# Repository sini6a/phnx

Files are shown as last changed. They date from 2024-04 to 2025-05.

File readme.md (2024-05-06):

# PHNX Keyboard

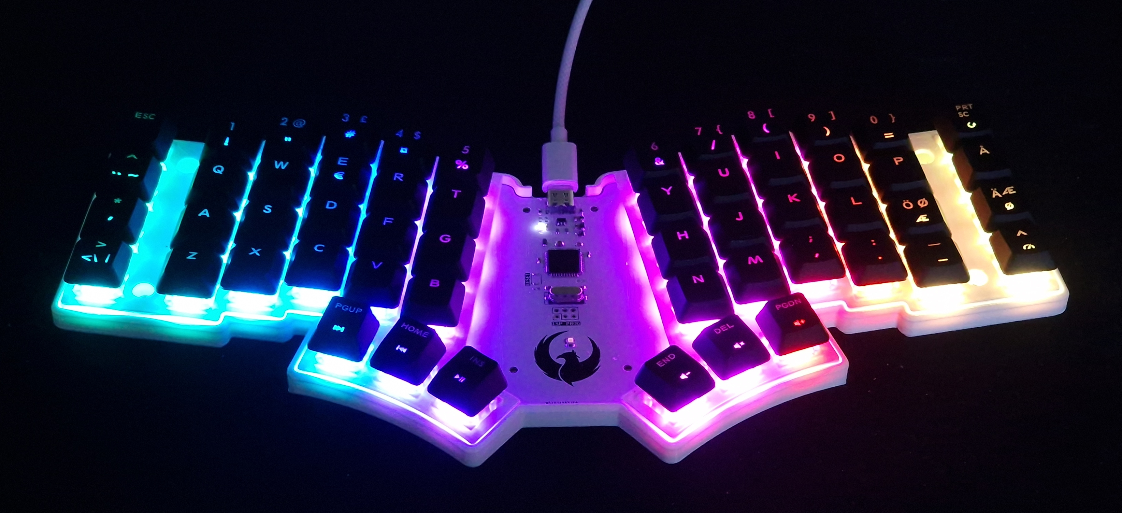
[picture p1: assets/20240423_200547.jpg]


PHNX is an ergonomic keyboard featuring 54 MX compatible switches. It is inspired by the Miryoku layout and includes one additional row at the top along with macro keys on both sides. Powered by the famous ATMega32U4 microcontroller, it features a Type C connector with ESD protection.

The keyboard is using QMK software and features an addressable LED on each key. Designed using KiCad 8, the boards were sponsored by [PCBWay](https://pcbway.com/), known for their excellent PCB manufacturing capabilities.

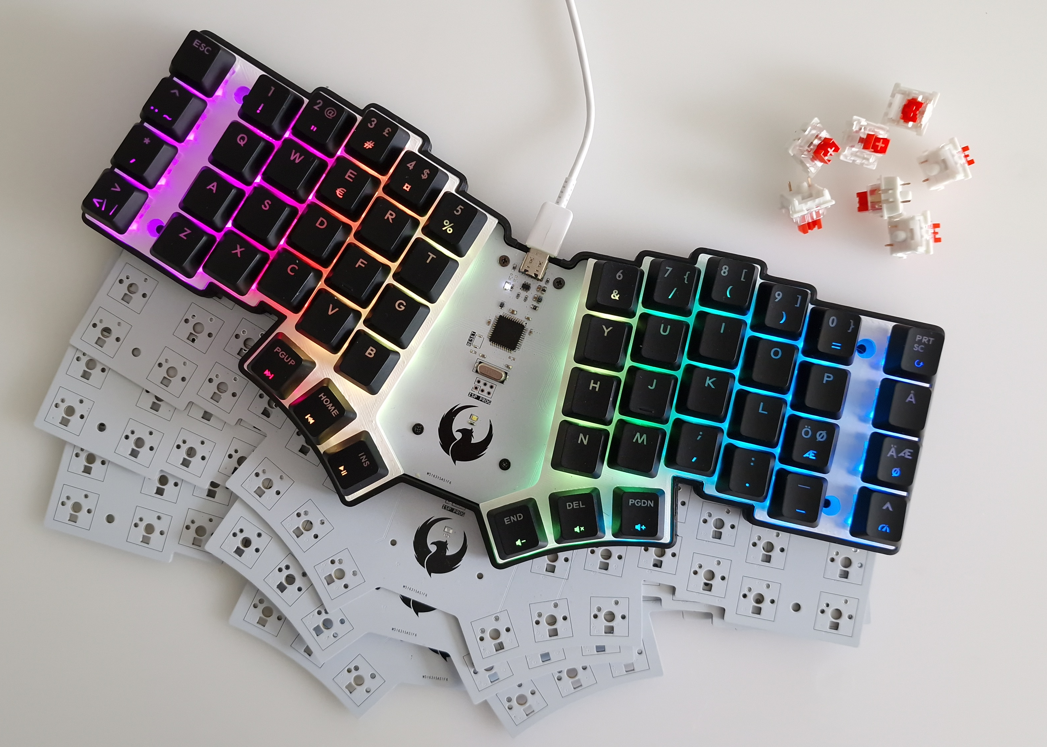
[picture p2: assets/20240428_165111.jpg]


## Project Structure

The project repository is structured as follows:

- **`kicad/`**: Contains PCB design files and schematics.
- **`gerbers/`**: Includes Gerber files essential for manufacturing.
- **`fimware/`**: Includes PHNX keyboard mappings and QMK files. This folder should be copied to your QMK directory and renamed to 'phnx'.
- **`case/`**: Consists of 3D print files for both the switch plates and the back cover of the keyboard.

The schematic is available in PDF format in the **`kicad/`** directory.

## Build Process

For a comprehensive overview of the schematic, board layout, and the build process, please refer to the following YouTube video:

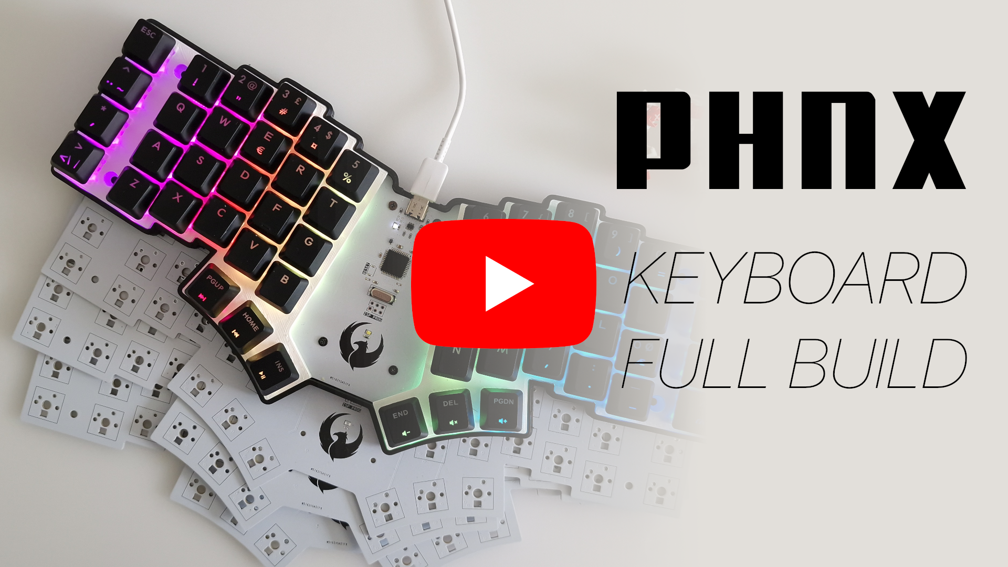
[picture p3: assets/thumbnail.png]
Thumbnail (https://www.youtube.com/watch?v=Z5Uw6cO_Igg)


## 3D Printed Parts

The case consists of two 3D printed parts. The two plates for each side to put switches on, and the bottom case which will fit the boards. The case has space for installing rubber pads for better grip.

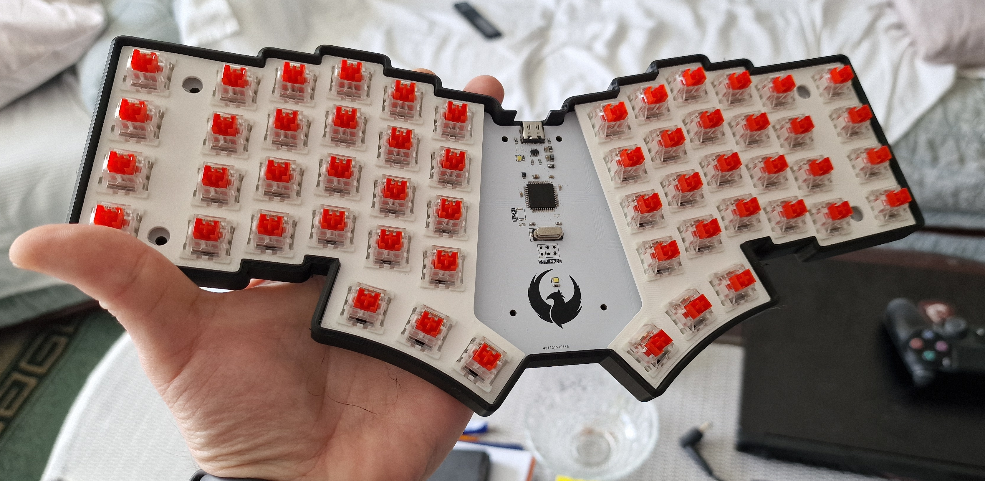
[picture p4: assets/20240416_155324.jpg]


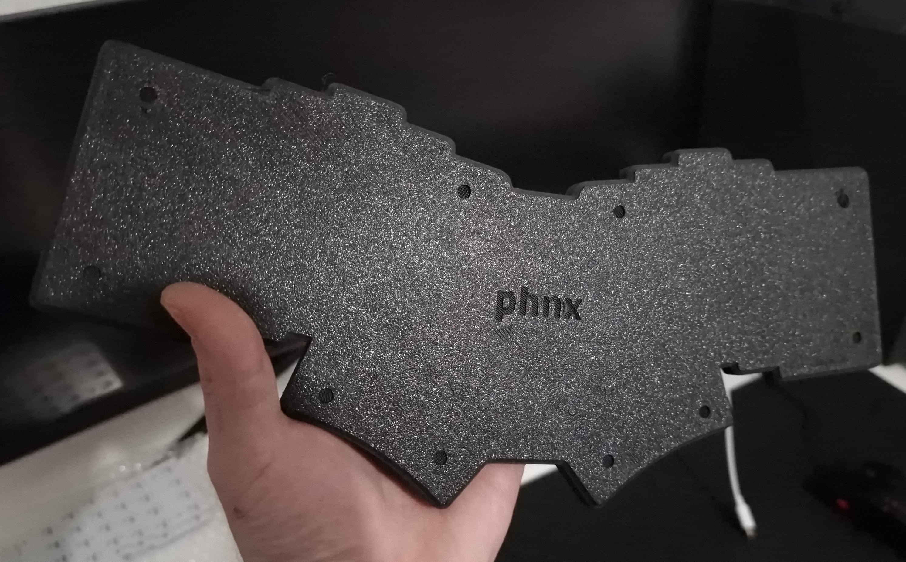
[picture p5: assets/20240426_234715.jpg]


## Contributing

Contributions to PHNX are welcome! Before making any changes, please ensure to open an issue to discuss the proposed modifications.

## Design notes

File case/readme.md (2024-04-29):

# 3D Files

The case is designed in Fusion 360 and the files are exported in STEP extension. 

For assembly we need 4xM2 screw inserts for the middle section of the case. The Component Cover needs redesign because it won't fit with the plates in place.

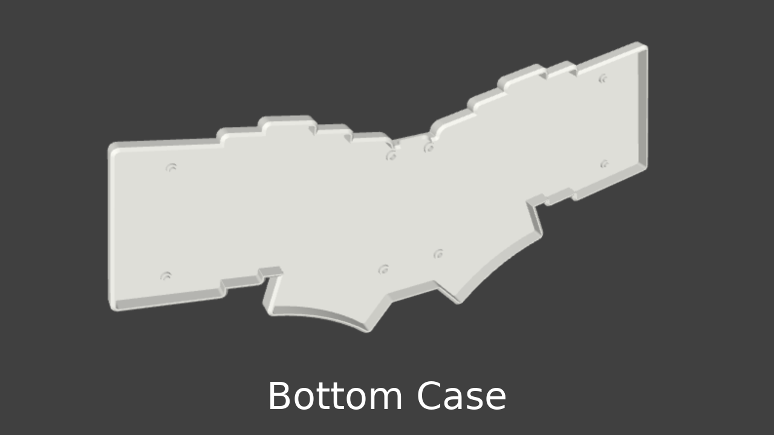
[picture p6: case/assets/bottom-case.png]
Bottom Case


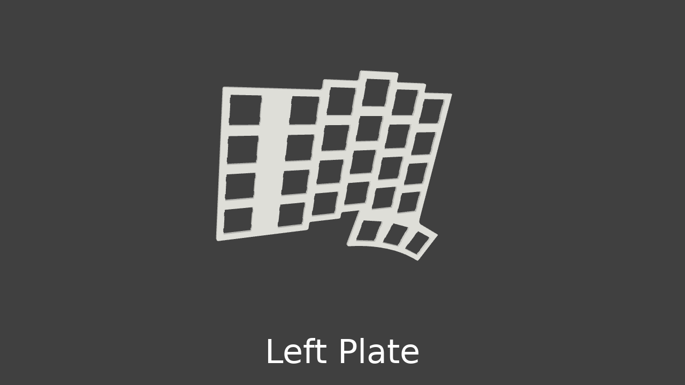
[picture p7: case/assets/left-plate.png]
Left Plate


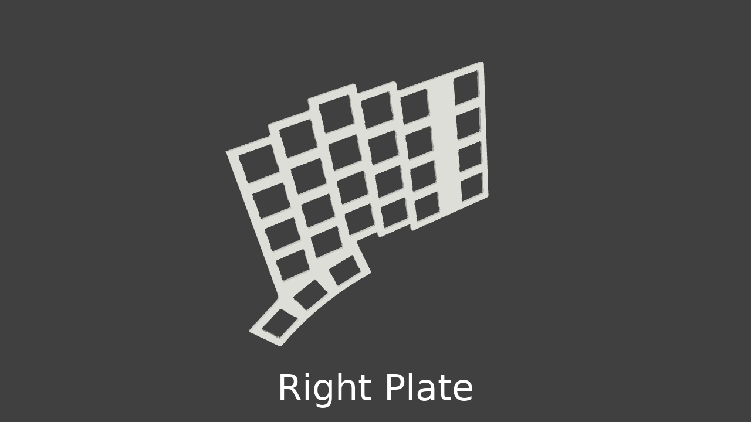
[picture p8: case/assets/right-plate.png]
Right Plate


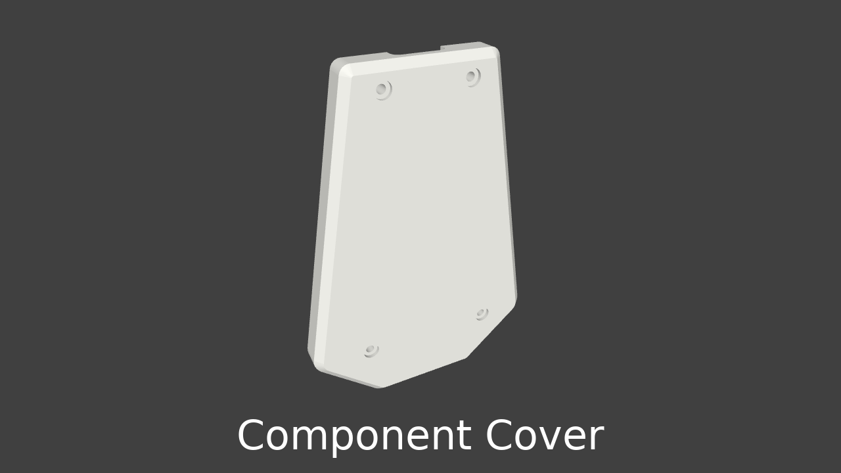
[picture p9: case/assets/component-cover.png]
Component Cover


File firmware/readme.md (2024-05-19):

# PHNX Firmware Files

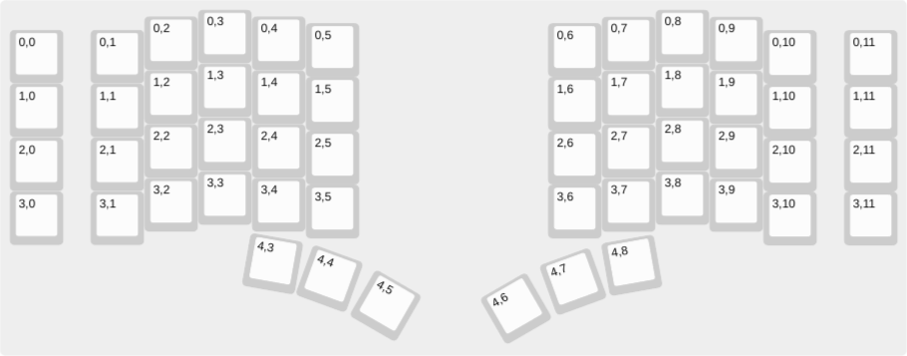
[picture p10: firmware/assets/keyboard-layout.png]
KLE


## Introduction

This directory contains firmware files for the PHNX keyboard, which is compatible with [QMK](https://github.com/qmk/qmk_firmware).

## Getting Started

To get started, follow these steps:

### 1. Clone QMK Firmware Repository

Ensure you have the latest version of QMK firmware on your local computer. Clone the QMK repository using the following command:

```bash
git clone https://github.com/qmk/qmk_firmware
```

### 2. Create PHNX Directory

Create a new directory named `phnx` in the `keyboards` directory in your local QMK:

```bash
mkdir qmk_firmware/keyboards/phnx
```

### 3. Copy Firmware Files

Copy the contents of the `firmware` directory from this repository to the newly created `phnx` directory in your QMK firmware repository:

```bash
cp -r path/to/phnx/firmware qmk_firmware/keyboards/phnx/
```

_Replace `path/to/phnx` with the actual path to the firmware directory in this repository._

## Compilation

Compile the keyboard firmware using the default or via keymap. You can do this using either the `make` command or the QMK client for Linux.

### Using Make

```bash
make phnx:default
```

or using `via` keymap:

```bash
make phnx:via
```

### Using QMK Client

```bash
qmk compile -kb phnx -km default
```

alternatively:

```bash
qmk compile -kb phnx -km via
```

## Flashing the Keyboard

Once the compilation is successful, you can proceed to flash the firmware onto the keyboard.

### Using Make

```bash
make phnx:default:flash
```

alternatively:

```bash
make phnx:via:flash
```

### Using QMK Client

```bash
qmk flash -kb phnx -km default
```

alternatively:

```bash
qmk flash -kb phnx -km via
```

**Note:** Depending on your system configuration, you may need to use `sudo` to flash the keyboard.

## Troubleshooting

If you encounter any issues during the compilation or flashing process, feel free to open an issue in this repository for assistance or check the official QMK repository.

Happy typing!

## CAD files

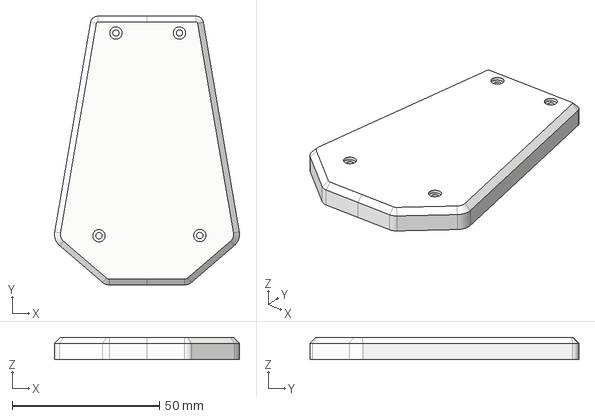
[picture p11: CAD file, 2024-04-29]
case/Component Cover.step
62.8 x 91.3 x 7.50 mm

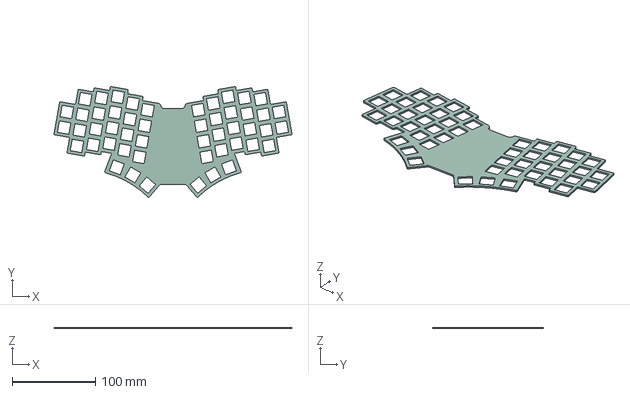
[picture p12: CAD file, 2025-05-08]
kicad/3D Exported/plate.step
286.3 x 133.4 x 1.60 mm

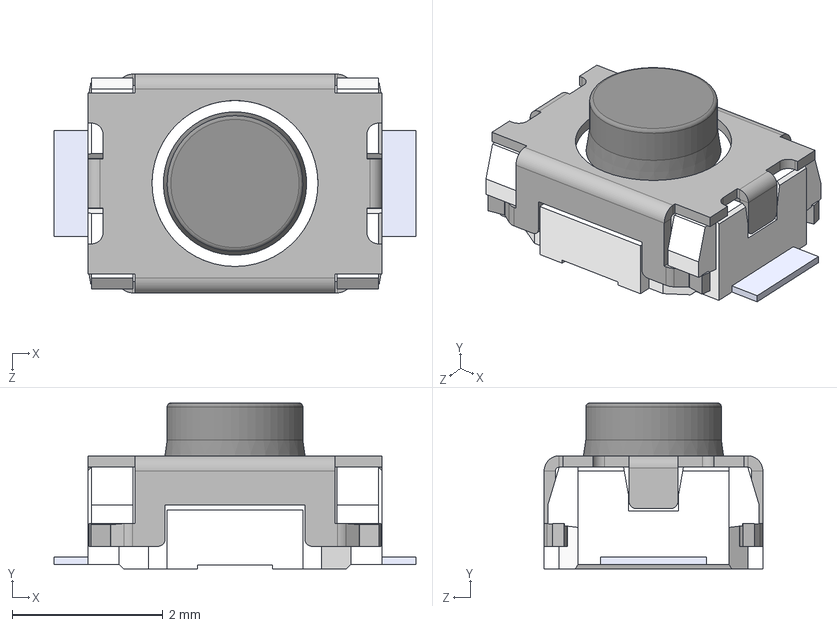
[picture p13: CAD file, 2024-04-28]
kicad/KiCad/3dmodels/SKRKAHE020--3DModel-STEP-56544.STEP
4.80 x 2.20 x 2.90 mm

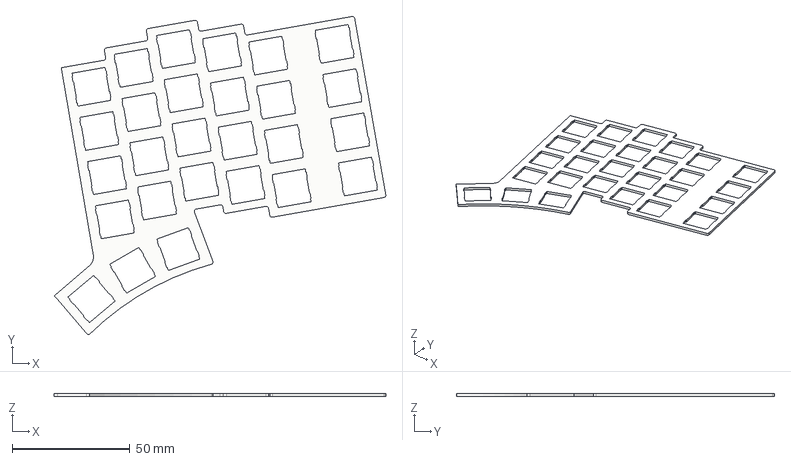
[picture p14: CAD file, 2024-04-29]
case/Right Plate.step
140.8 x 135.0 x 1.30 mm

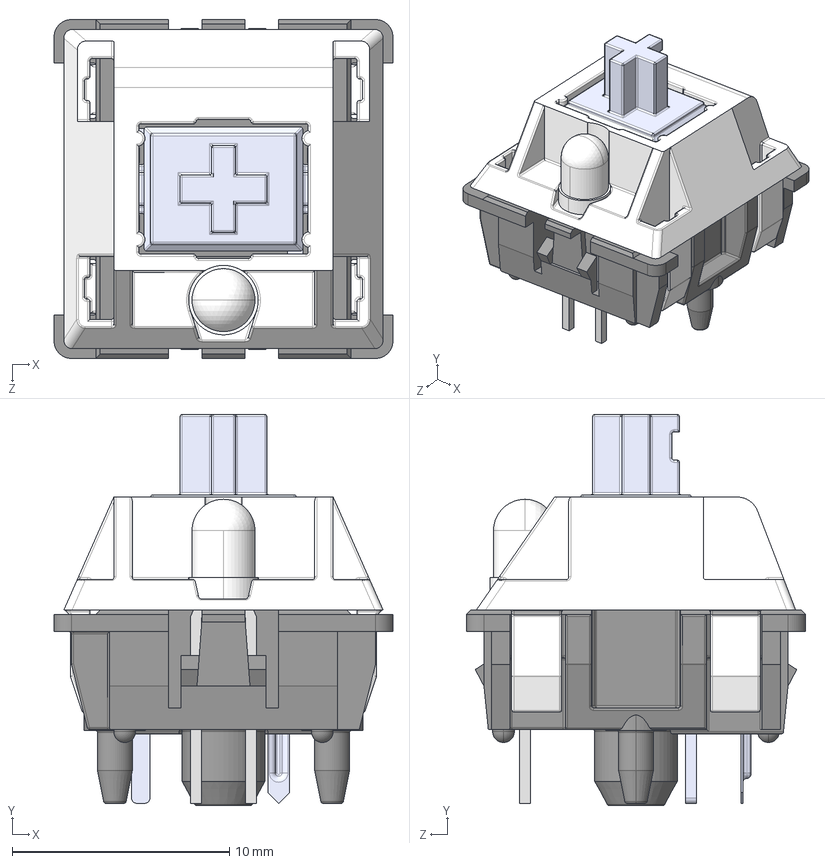
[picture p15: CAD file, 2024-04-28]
kicad/KiCad/3dmodels/Cherry MX.STEP
15.6 x 18.0 x 15.6 mm
Bottom
Pulsador
Top
Pieza5^Cherry MX
Pin1
Pin2
Led 3mm_trans

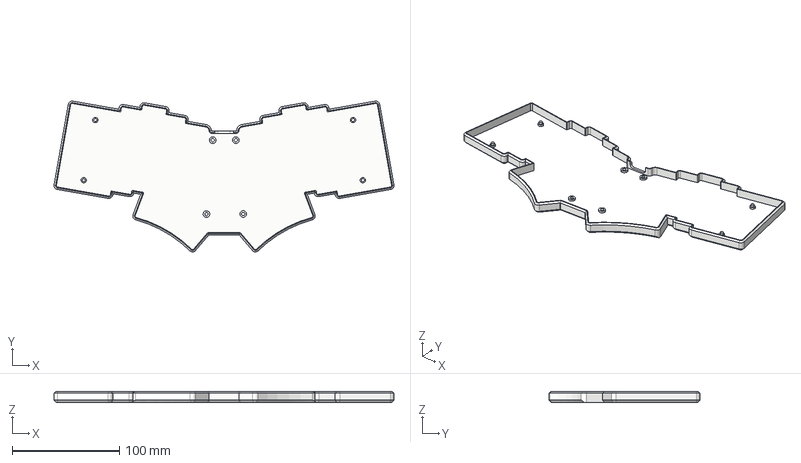
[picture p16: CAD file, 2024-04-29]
case/Bottom Case.step
316.5 x 140.5 x 10.0 mm

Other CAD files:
case/Left Plate.step

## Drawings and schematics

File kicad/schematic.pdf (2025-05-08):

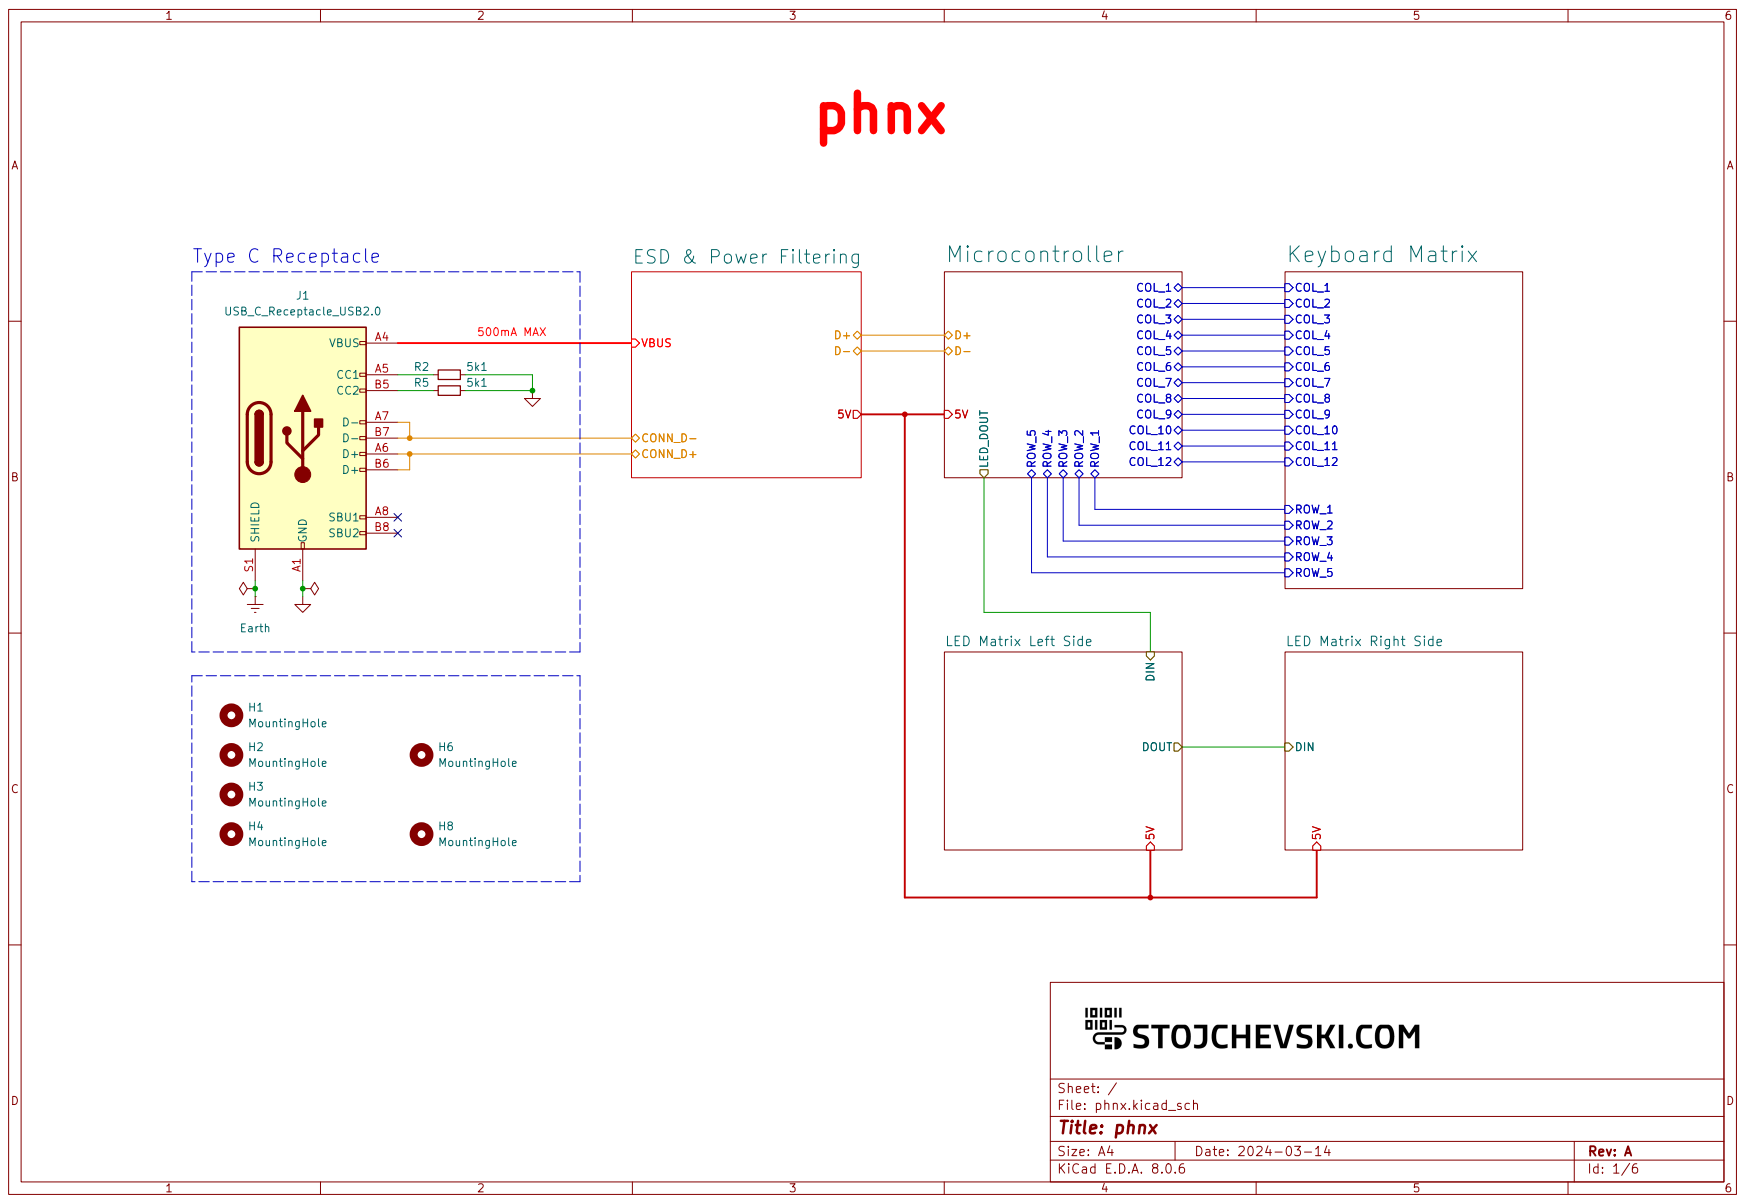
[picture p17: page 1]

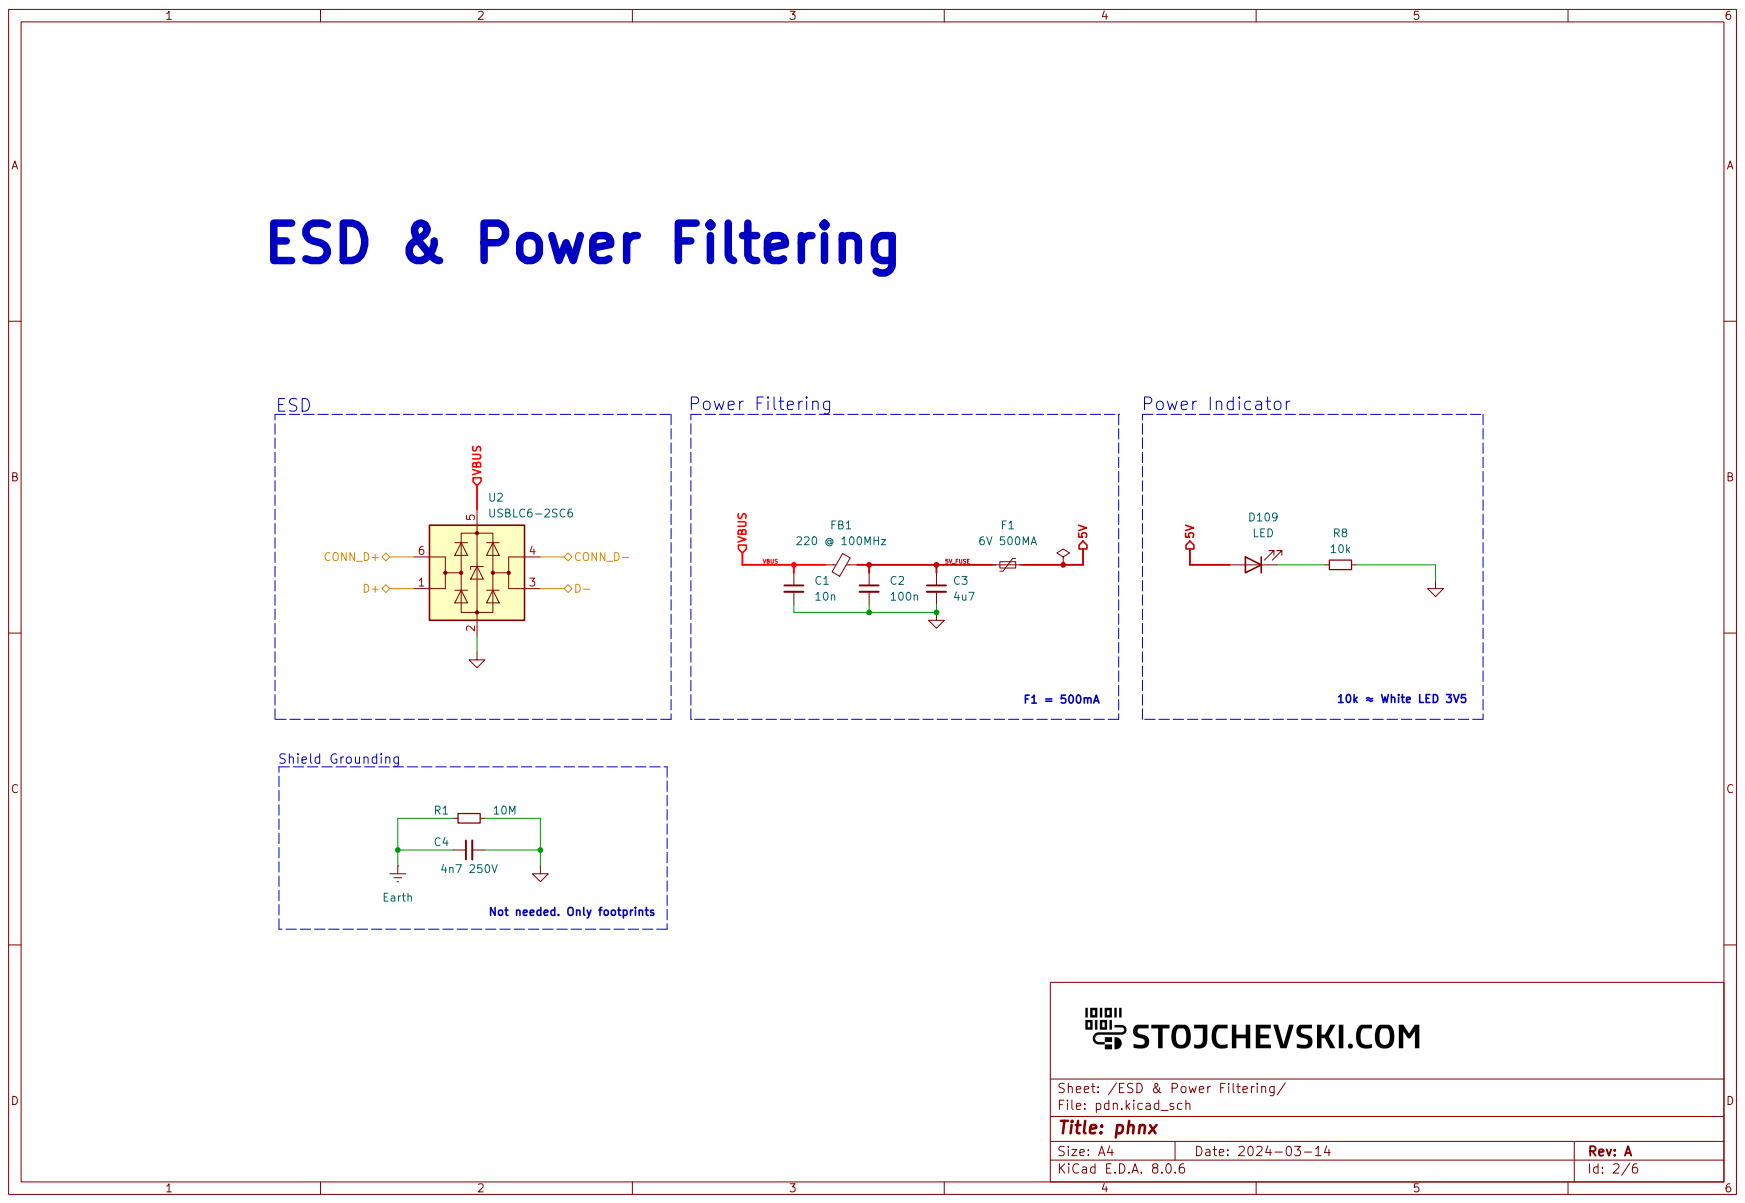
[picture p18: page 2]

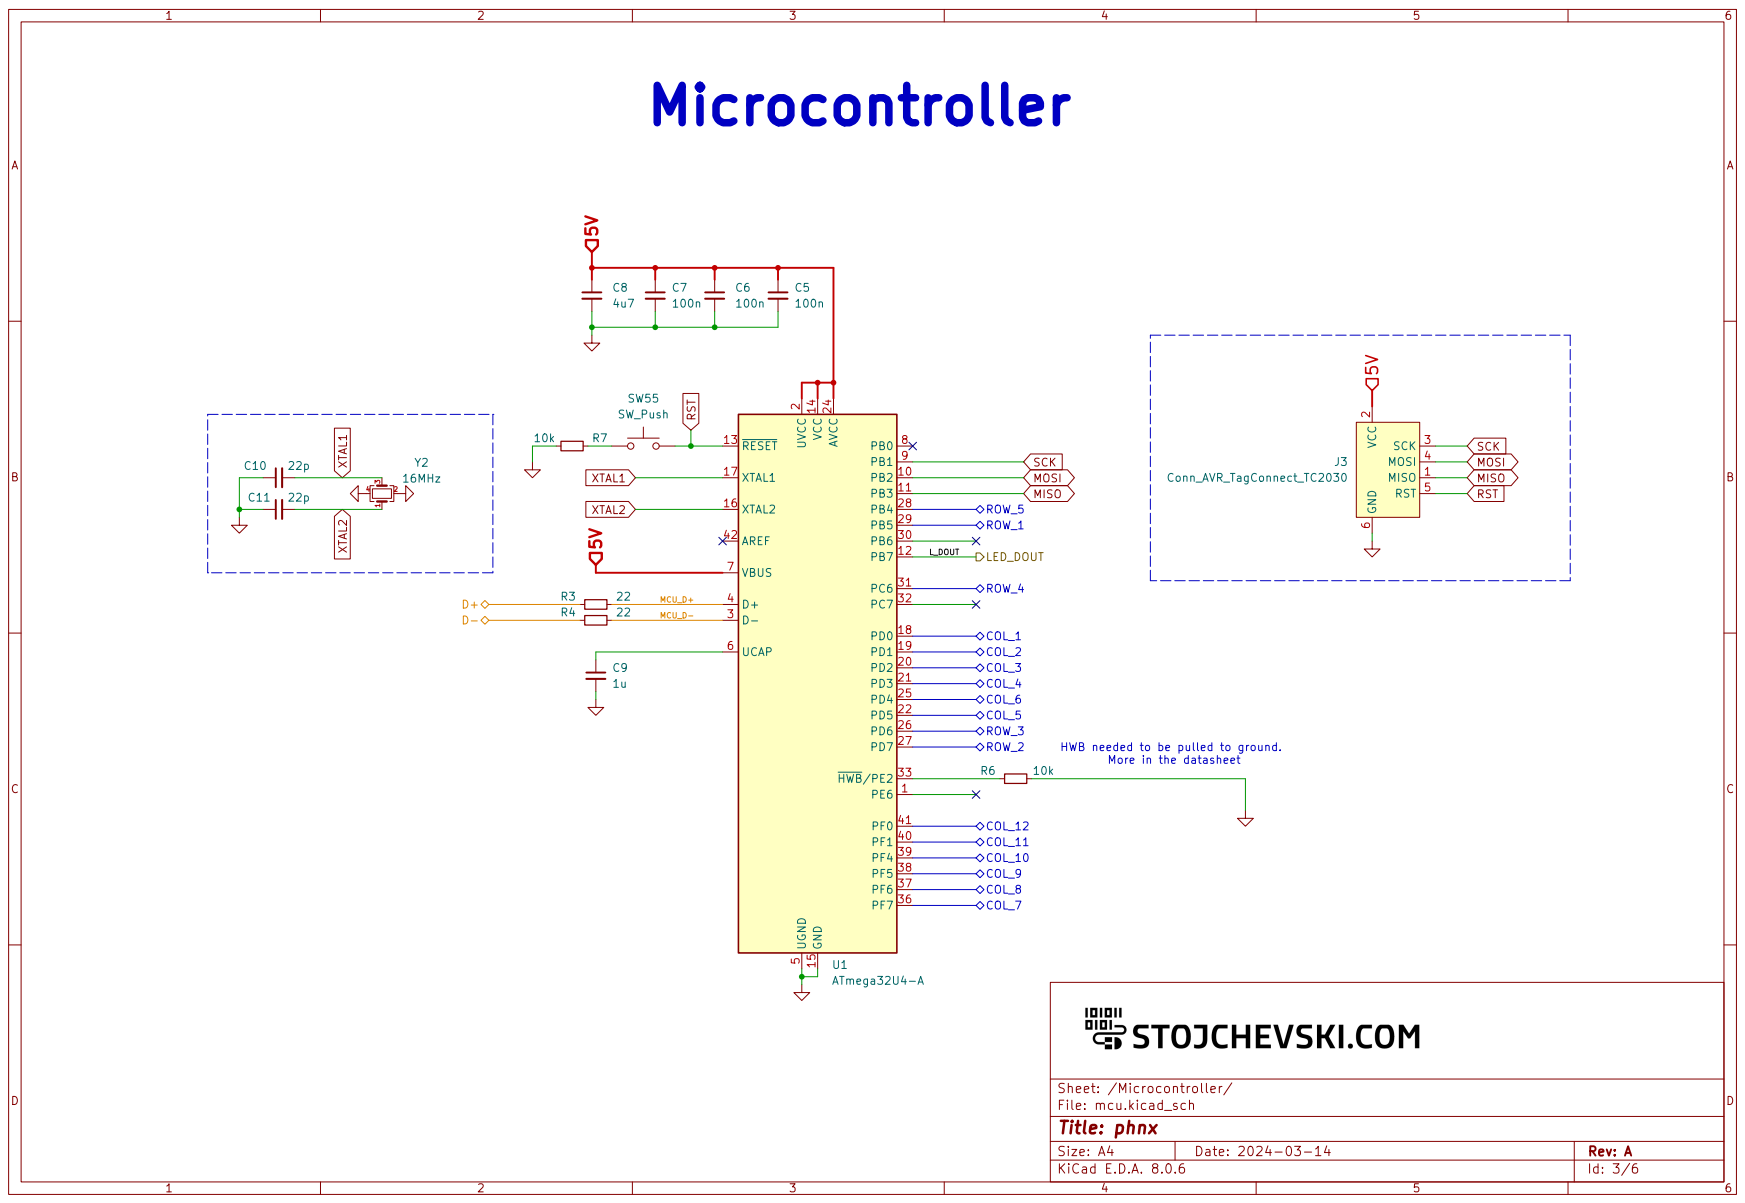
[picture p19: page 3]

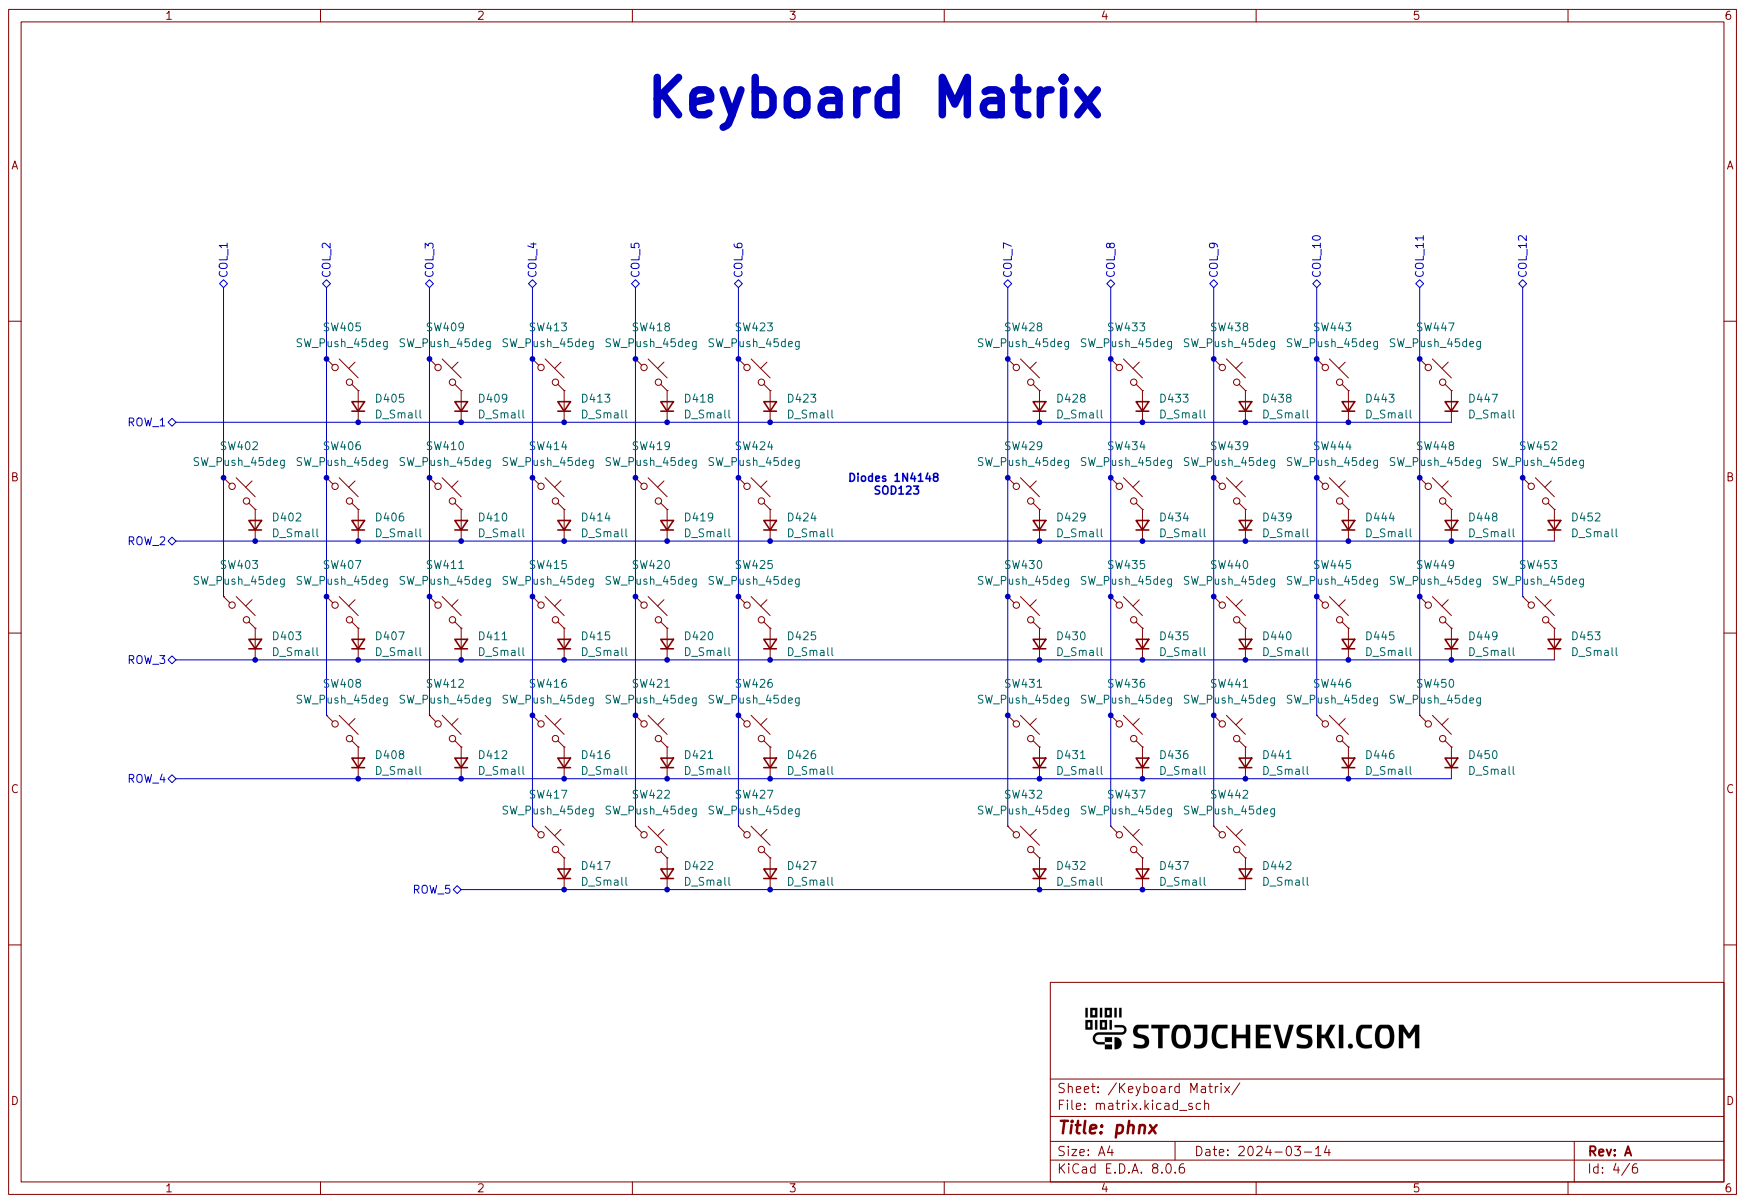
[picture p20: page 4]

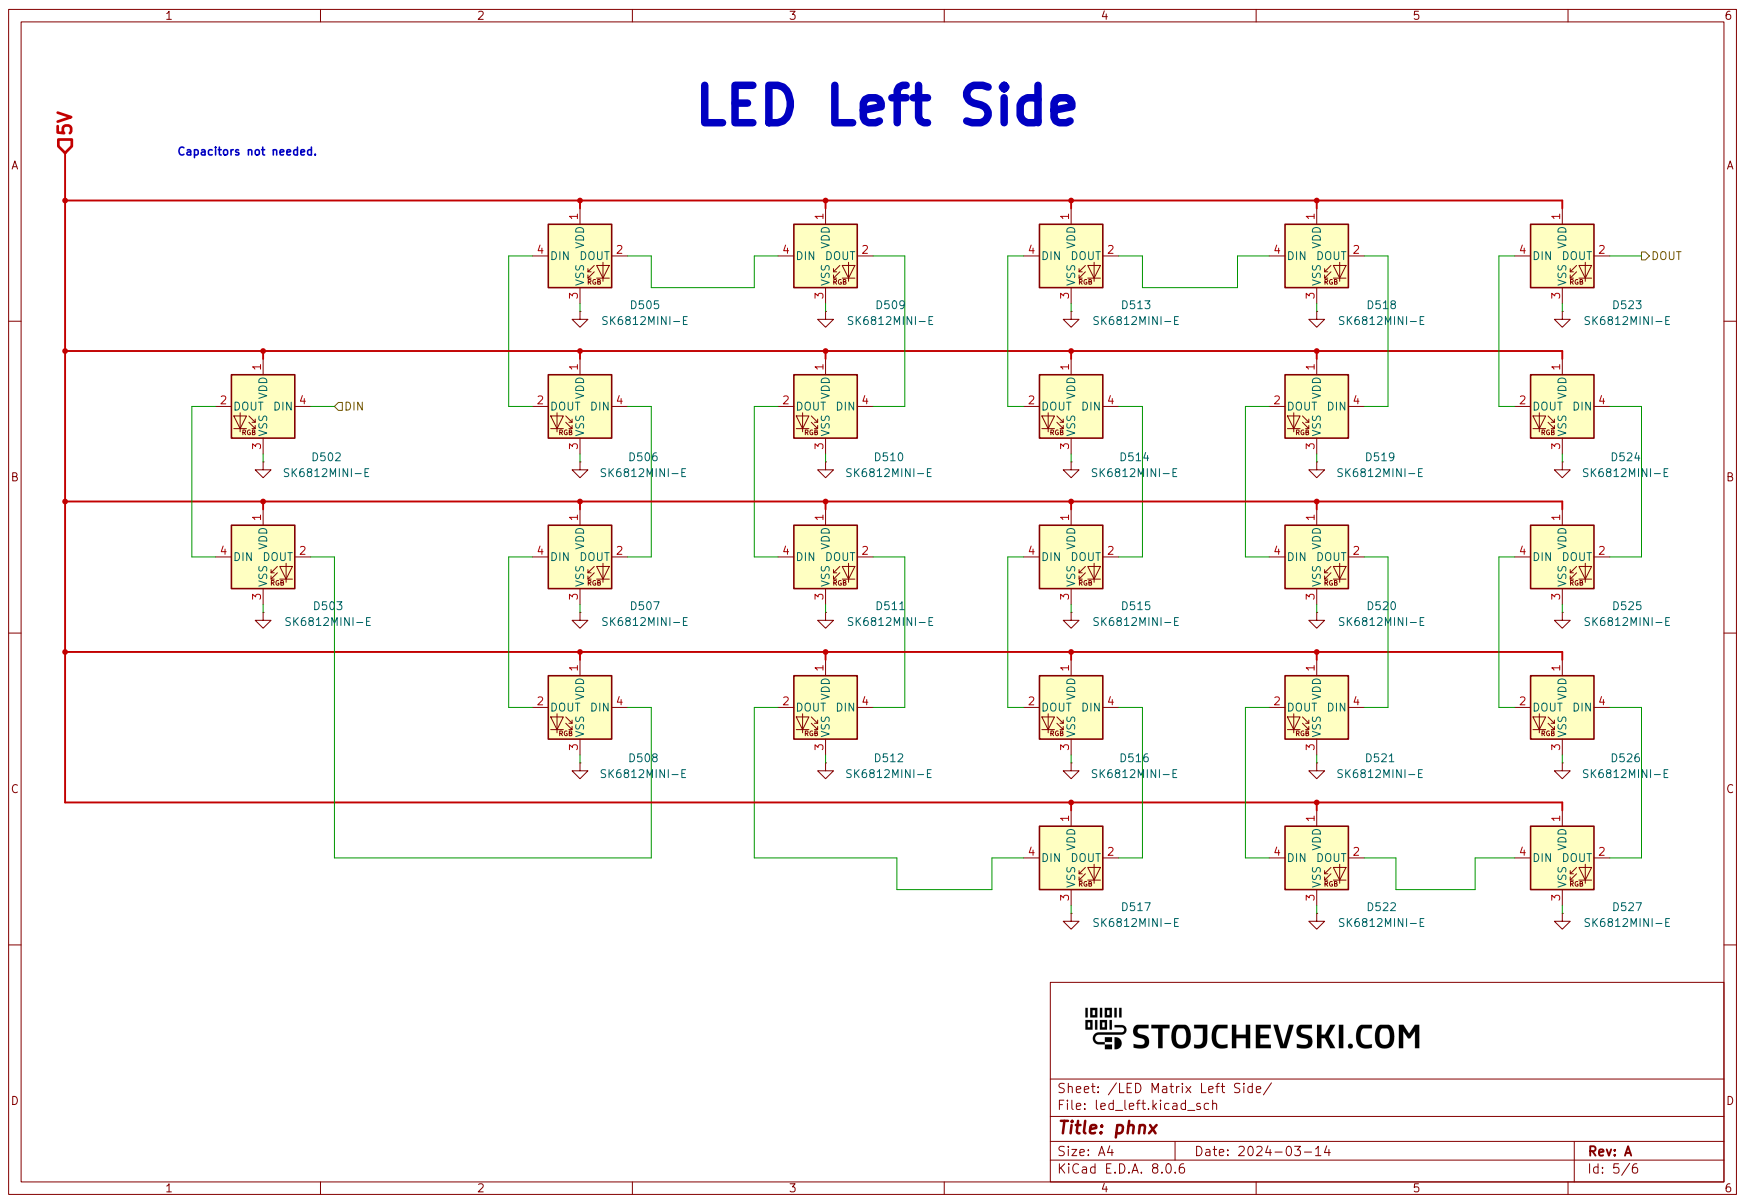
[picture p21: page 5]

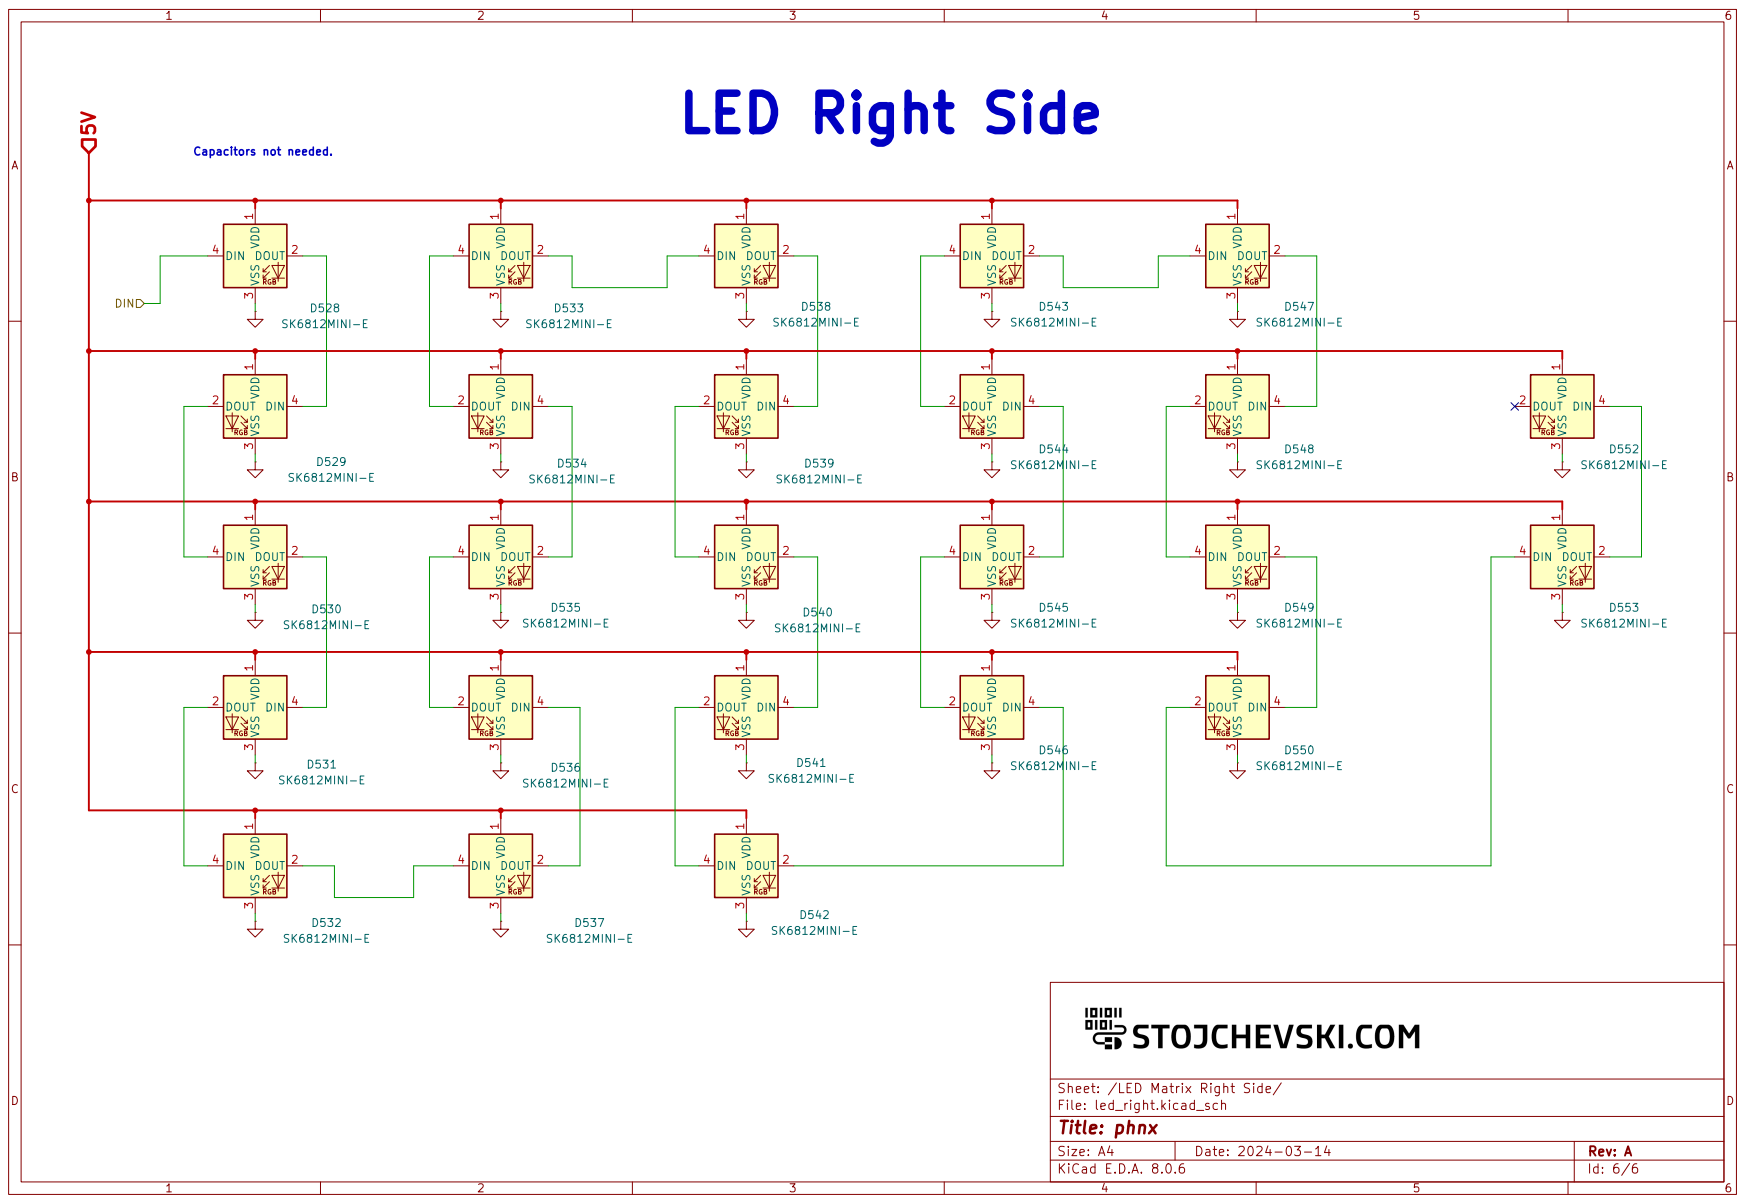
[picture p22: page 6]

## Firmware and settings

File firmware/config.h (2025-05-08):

// Copyright 2024 Sinisha Stojchevski (@sini6a)
// SPDX-License-Identifier: GPL-2.0-or-later

#pragma once

/* Hold the ESC key while plugging in the keyboard to enter bootloader mode */
#define BOOTMAGIC_KEY_SALT KC_NO    // No modifier needed
#define BOOTMAGIC_KEY_SALT2 KC_NO   // No second modifier needed
#define BOOTMAGIC_KEY_BOOT KC_TILDE   // Press 'KC_TILDE' key

/* RGB Configuration for SK6812 MINI-E LED */
#define WS2812_DI_PIN B7
#define RGBLIGHT_LED_COUNT 54

#define RGBLIGHT_EFFECT_ALTERNATING
#define RGBLIGHT_EFFECT_BREATHING
#define RGBLIGHT_EFFECT_CHRISTMAS
#define RGBLIGHT_EFFECT_KNIGHT
#define RGBLIGHT_EFFECT_RAINBOW_MOOD
#define RGBLIGHT_EFFECT_RAINBOW_SWIRL
#define RGBLIGHT_EFFECT_RGB_TEST
#define RGBLIGHT_EFFECT_SNAKE
#define RGBLIGHT_EFFECT_STATIC_GRADIENT
#define RGBLIGHT_EFFECT_TWINKLE

#define RGBLIGHT_DEFAULT_MODE RGBLIGHT_MODE_RAINBOW_SWIRL
#define RGBLIGHT_LIMIT_VAL 120

#define RGBLIGHT_SLEEP

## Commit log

2024-04-29 updated 3d parts
    [Bottom Case.step, Component Cover.step, Left Plate.step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]
2025-05-08 moved to revision b
    [led_left.kicad_sch, led_right.kicad_sch, matrix.kicad_sch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]
